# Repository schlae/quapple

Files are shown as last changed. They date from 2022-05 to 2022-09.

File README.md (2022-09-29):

# Quapple - A Quadlink Clone
What is a Quadlink? It's an ISA expansion card from the '80s designed to turn your IBM PC (such as a 5150 or 5160) into an Apple \]\[! After booting and running the software, you can switch quickly between PC and Apple mode using Ctrl-Alt-A (for Apple) and Ctrl-Alt-P (for PC).

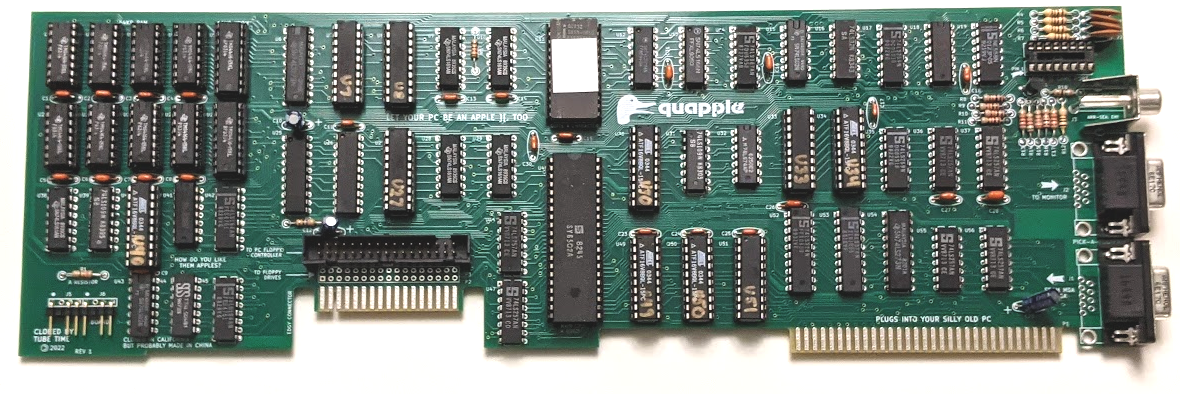
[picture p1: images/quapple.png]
Quapple card photo


I'm not selling this board, but the complete design files are available here so you can build it yourself. As an alternative, [a2heaven](http://www.a2heaven.com/webshop/index.php?rt=product/product&product_id=177) sells a kit with the PCB and all the components. (I have not personally built one of these kits.)

All of the components are readily available. In the bill of materials, Mouser part numbers are listed where available. The RAM chips, 27C32 ROM chip, and NE558 may be obtained from a variety of sources in China, but they are not guaranteed to work, so I recommend getting 1 or 2 extras just in case. Note: It has been reported that a Signetics NE558 with a date code of 8825VI, commonly available from China, does not actually work. If you can't find any working 558 chips, try building [my replacement that uses four 555 chips](https://oshpark.com/shared_projects/zHGURt7g).

[Schematic](https://github.com/schlae/quapple/blob/main/Quapple.pdf)

[Bill of Materials](https://github.com/schlae/quapple/blob/main/Quapple.csv)

Please note that the 0.1" header pins are *not* listed on the BOM. They are standard breakaway headers.

The memory chips (4416 and 4164 RAM) are both 150ns types.

[Fab Files](https://github.com/schlae/quapple/blob/main/fab/Quapple-rev1.zip)

## Fabrication Notes
This board is a straight forward 2-layer board. Ideally you should specify selective gold plating (hard gold) for the edge fingers, but this gets very expensive for small orders. ENIG will work but the gold will rub off fairly quickly.

Board dimensions are 13.335" x 4.24" (338.7mm x 107.7mm).

For the soldermask color, pick whatever you want!

## Assembly Notes
I recommend using sockets for the memory chips, CPU, and all the PALS. You'll also need a socket for the joystick/paddle connector. The list of sockets required is as follows:

| Quantity |  Position | Type |
|---|---|---|
| 9 | U1-U4, U20-U23, J4 | 16-pin, 0.3" wide |
| 2 | U5, U24 | 18-pin, 0.3" wide |
| 1 | U11 | 24-pin, 0.6" wide |
| 1 | U48 | 40-pin, 0.6" wide |
| 10 | U7, U8, U27, U30, U33, U34, U40, U49, U50, U51 | 20-pin, 0.3" wide |

If you plan to install the card in an IBM 5150 or 5160, you'll plug the floppy drive cable (the one going between the existing controller and the floppy drives in your computer) into the P2 edge connector on the card. **Solder a shrouded header at the J7 position with the keying notch pointing downwards.** Later on, you'll make a short cable to go between the floppy controller card and J7.

If you want to use the card in another system (note: I have not tested this yet!) with a standard IDC header instead of an edge card connector, **solder unshrouded headers at both the J7 and P3 position.** Your existing floppy cable will plug into P3, and you will need to make a short cable that connects J7 and your existing floppy controller card.

J5 and J6 are right-angle 0.1" headers. You can use a single 8-pin strip. Remember to pull pin 2 on both header positions since this is the key for the cable that plugs in. This is also marked on the back of the PC board.

If you are using an NMOS 6502, you can connect the solder jumper on the back of the board right next to the chip. CMOS 6502 chips repurpose this pin and the solder jumper should be left open.

Note for European users: it might be tempting to configure the solder jumpers on the back of the card for PAL timings rather than NTSC, but I have not tested this configuration. The original Quadlink has solder paste covering the jumpers, implying that they never fully tested it. Use it at your own risk.

## Bracket
I've created a CAD model of the original Quadlink bracket. If you have access to sheet metal tools (or even just a chassis nibbler) then you can reproduce it. Once it is in the right shape, bend the top using a press brake or even just a bench vise. The material is 0.035" (0.9mm) steel, brushed and painted black.

[CAD drawing of bracket](https://github.com/schlae/quapple/blob/main/mech/bracket.dxf)

## Programmable Devices
There are 11 programmable devices on the Quapple. One of them is a 27C32 EPROM which contains the character set for the text mode. I didn't have much luck using the Minipro TL866 device to program my Intel 2732 devices, so you might have to try a few to find one that works. You might also try using a flash device (28C32?) instead, but I have not tested this myself.

[EPROM binary](https://github.com/schlae/quapple/blob/main/eprom/U11QL100.bin)

The remaining programmable devices are all PALs. You can use an ATF16V8 (speed grade is unimportant here), which happens to be supported by the Minipro TL866.

[PAL files](https://github.com/schlae/quapple/tree/main/pals)

Use the JEDEC files (.jed) with the following Minipro command line under Linux:

`minipro -p "ATF16V8B" -w [file.jed] -P`

The full, commented, PAL source code is provided for educational purposes. If you want to modify them, you can use WinCUPL to build them.

I recommend marking the PALs with colored dots, labels, or permanent marker so you don't mix them up and put them in the wrong sockets.

PAL functions are as follows:

| Position | Function |
|---|---|
| U8 | Video address decoding (simple) |
| U27 | Video address decoding (complex). Video sync. |
| U7 | Clock generation |
| U30 | Soft switches |
| U33 | Color attribute generation |
| U34 | ISA bus address decoder |
| U40 | Disk controller |
| U49 | 6502 state machine |
| U50 | More soft switches |
| U51 | RAM/ROM mapping, CAS control, RESET inverter |

## Cable assemblies
You will also need to build several cable assemblies to connect the Quapple to your PC.

### Floppy drive cable
For use with an IBM 5150 or 5160, make a short, 6" (15cm) IDC ribbon cable, 34 pin, with a 0.1" female header at one end and a 34-pin female edge connector at the other end.

For any other computer, just crimp a 34-pin 0.1" female header at both ends. Be sure not to get pin 1 mixed up--it is very easy to do!

### Video loopback cable
To use the same monitor for both Apple and PC mode, you'll need a short cable to go between the Quapple and your regular video card (MDA or CGA). This is just a short cable with a male DE-9 connector at both ends, wired straight through (pin 1 to pin 1, etc).

The stock cable is 12" (30.5cm) long and uses a TE Connectivity/AMP 745032-1 connector, along with a cord guard, 207753-1, at both ends. The contact part number is 1-66506-0. The cable is 0.24" (6mm) diameter with eight conductors (the drain wire is connected to pin 1).

### PC speaker jumper
To hear Apple sound through the PC speaker, make a short 2-wire cable (maybe 2-3" long, depending on your computer). This goes from the motherboard to the Quapple.

The cable should be wired as follows:

* Pin 1 connects to pin 1 (black wire)
* Pin 2 is a key (plastic peg inserted in the opening) at both ends
* Pin 3 is not used
* Pin 4 to pin 4 (yellow wire)

## Installation
You'll want to install the card in the second-to-last slot (5150) or third-from-last slot (5160). This is because the floppy controller should be in between the Quapple and the power supply, just to make cable routing easier.

Before you start, plug the short floppy jumper cable into J7 on the Quapple. Also plug the 4-pin PC speaker jumper cable into header J6.

Remove the floppy controller and disconnect the drive cable from it. Plug the drive cable into the Quapple connector P2 (or P3, if the cable has a 0.1" socket at the end). Unplug the PC speaker from the motherboard.

Then plug the Quapple into the PC slot, managing the floppy cable as needed. The 4-pin jumper should plug into the motherboard's PC speaker header, and the PC speaker cable should plug into J5.

Then plug the short floppy jumper cable into the header on the floppy controller, and plug the floppy controller back into an adjacent slot. Since the card is shorter, it's much easier to use the slot that is closer to the power supply.

Finally, connect the DE-9 jumper cable between the video card and the *lower* connector on the Quapple. This step is optional since you can use the card with a dual monitor configuration, or even with the composite video output jack.

## Software
You can find the software at the link below, along with the manual of the original Quadlink. There are *three* disk images you will need: the Quadlink System Master, the Quadlink Filer, and DOS (I used PC DOS 1.10, but feel free to experiment). The Quadlink System Master disk has an executable, QUADLINK.EXE, which should be copied to the DOS disk.

The Filer disk can be written using a flux imaging tool, or possibly with an Apple II running ADTPro.

[Software download](https://www.diskman.com/presents/trackstar/software.htm)

A note about compatibility: I have only tested the card in an IBM 5150. It's supposed to work in a 5160 as well. Based on looking at the design, I see no reason why it wouldn't work in a faster machine, but there may be CPU-dependent hardware loops in the Quadlink executable that would prevent it from working.

Once you have the disks, insert the DOS disk and turn on the computer. After it boots, run QUADLINK.EXE and follow the prompts. When you insert the Filer disk, the software copies the entire Applesoft ROM from the disk into a special 16K memory on the card and write-protects it. Hit a key to get back to DOS, and then press CTRL-ALT-A. If you see the Quadlink banner, hit CTRL-ALT-DEL to boot the Apple.

## Troubleshooting
This can be a tricky card to troubleshoot. The QUADLINK.EXE doesn't really provide good error diagnostics, but if you can get it to access the Filer disk, then you know that the 6502 is running code and trying to copy data from the disk.

Someday, when I get a chance, I'll look into writing a diagnostic program to help with the process...

## License
This work is licensed under a Creative Commons Attribution-ShareAlike 4.0
International License. See [https://creativecommons.org/licenses/by-sa/4.0/](https://creativecommons.org/licenses/by-sa/4.0/).

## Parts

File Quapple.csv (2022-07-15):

Item | Qty | Reference(s) | Value | Mouser
1 | 23 | C1, C2, C3, C4, C5, C6, C7, C8, C11, C13, C14, C15, C16, C17, C18, C23, C24, C25, C26, C27, C28, C30, C31 | 0.1uF | 594-K104K15X7RF5TH5
2 | 1 | C9 | 0.1uF | 594-K104K15X7RF5TH5
3 | 3 | C10, C12, C29 | 6.8uF | 667-ECA-1HM100I
4 | 4 | C19, C20, C21, C22 | 0.02uF | 81-RDE7U3A203JUE1H3A
5 | 1 | J1 | PC VIDEO IN | 523-G17C0900132EU
6 | 1 | J2 | MONITOR OUT | 523-G17C0900132EU
7 | 1 | J3 | COMP | 502-3517PCX
8 | 1 | J4 | PADDLES | 517-4816-3004-CP
9 | 1 | J5 | TO SPEAKER | 538-22-28-6043
10 | 1 | J6 | FROM MOTHERBOARD | 538-22-28-6043
11 | 1 | J7 | PC_CTLR | 571-5103308-7
12 | 2 | JP1, JP2 | OPEN
13 | 1 | JP3 | SHORT
14 | 1 | JP4 | SHORT
15 | 1 | JP5 | OPEN
16 | 1 | JP6 | VPB
17 | 1 | P1 | Conn_ISA_8bit
18 | 1 | P2 | EDGE_TO_DRIVES
19 | 1 | P3 | TO_DRIVES | 571-5103308-7
20 | 1 | Q1 | 2N3904 | 610-2N3904
21 | 1 | R1 | 33 | 603-CFR-25JR-5233R
22 | 1 | R2 | 470 | 603-CFR-25JR-52470R
23 | 2 | R3, R15 | 3.3K | 603-CFR-25JR-523K3
24 | 5 | R4, R5, R6, R7, R12 | 100 | 603-CFR-25JR-52100R
25 | 4 | R8, R9, R10, R11 | 10K | 603-CFR-25JR-5210K
26 | 1 | R13 | 2.2K | 603-CFR-25JR-522K2
27 | 1 | R14 | 5.6K | 603-CFR-25JR-525K6
28 | 1 | R16 | 10K | 603-CFR-25JR-5210K
29 | 1 | R17 | 22K | 603-CFR-25JR-5222K
30 | 1 | R18 | 51 | 603-CFR-25JR-5251R
31 | 8 | U1, U2, U3, U4, U20, U21, U22, U23 | TMS4164
32 | 2 | U5, U24 | TMS4416
33 | 2 | U6, U54 | 74LS273 | 595-SN74LS273N
34 | 3 | U7, U33, U50 | PAL16R8 | 556-AF16V8CZ15PU
35 | 6 | U8, U27, U30, U34, U49, U51 | PAL16L8 | 556-AF16V8CZ15PU
36 | 5 | U9, U10, U28, U29, U38 | 74LS161 | 595-SN74LS161AN
37 | 1 | U11 | 27C32
38 | 1 | U12 | 74LS298 | 595-SN74LS298N
39 | 1 | U13 | 74LS166 | 595-SN74LS166AN
40 | 1 | U14 | 74LS367 | 595-SN74LS367AN
41 | 2 | U15, U43 | 74LS02 | 595-SN74LS02N
42 | 1 | U16 | 74LS32 | 595-SN74LS32N
43 | 2 | U17, U35 | 74LS259 | 595-SN74LS259BN
44 | 1 | U18 | 74LS251 | 595-SN74LS251N
45 | 1 | U19 | NE558
46 | 1 | U25 | 74LS373 | 595-SN74LS373N
47 | 1 | U26 | 74LS245 | 595-SN74LS245N
48 | 2 | U31, U39 | 74LS109 | 595-SN74LS109AN
49 | 1 | U32 | 74LS74 | 595-SN74LS74AN
50 | 6 | U36, U37, U46, U47, U55, U56 | 74LS257 | 595-SN74LS257BN
51 | 1 | U40 | PAL16R4 | 556-AF16V8CZ15PU
52 | 1 | U41 | 74LS38 | 595-SN74LS38N
53 | 2 | U42, U45 | 74LS194 | 595-SN74LS194AN
54 | 1 | U44 | 74LS04 | 595-SN74LS04N
55 | 1 | U48 | 6502 (NMOS) | 955-W65C02S6TPG-14
56 | 2 | U52, U53 | 74LS374 | 595-SN74LS374N

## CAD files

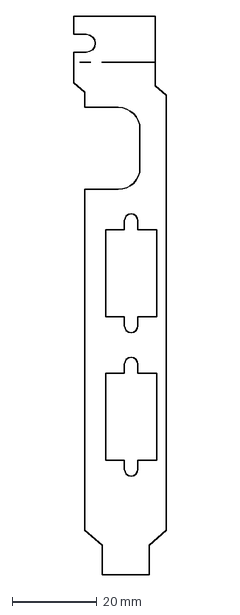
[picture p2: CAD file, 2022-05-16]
mech/bracket.dxf
21.8 x 131.4 mm

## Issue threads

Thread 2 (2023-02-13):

Intermittent operation

snhirsch, 2023-02-13:
Ok, so this is frustrating.  My newly-built Quapple worked the first time I put it in a 5150 and I was able to boot into the filer and DOS.  In the midst of testing, it started having problems writing to diskette.  From that point on, it refuses to boot.  When I hit return in Quadlink it tries a few times to read the FILER floppy before telling me it cannot read the diskette.  I reseated all the chips and swapped CPU.  No joy.  If I'm interpreting the writeup correctly, the seeks indicate the 6502 is executing code - is that correct?  If so, can you suggest a direction for diagnosis?  I have a fair amount of bench experience and own a scope and logic analyzer.

I recompiled the PLD sources for 8 of the 10 PLDs so I could target fused PALs (have a bunch of them).  But, the disk controller (U40) and clock generator (U7) are GAL16V8-20 per parts list.

schlae, 2023-02-13:
Since you had it working for a short time that makes me suspect either the drive itself or the Filer disk you're using, or perhaps the floppy data cable. You could try writing another Filer disk and going from there. If you have a logic analyzer, you could also connect a chip clip onto the disk decoding PAL and make sure you see signals that make sense.

But yes, if it tries to read from the disk then the 6502 is running code. That gets bootstrapped through the keyboard port (!) from the PC software side.

snhirsch, 2023-02-13:
Ok, good to know that something is running on the Quapple.  As a corrollary to my original question, do you have a guess as to why CUPL 4 won't compile the U40.PLD source?  I've attached the .LST and .DOC output files.  The latter complains of too many product terms.
[U40.zip](https://github.com/schlae/quapple/files/10723599/U40.zip)
This certainly isn't a showstopper, since I was able to program a GAL16V8 with your original JED, but my curiousity is getting the better of me.

I've already swapped the cabling and floppy drive and have re-written the media several times from a real Apple 2.  But it's possible the diskette is bad, so I'll revisit it.

snhirsch, 2023-02-14:
I'm starting to suspect an issue with the host machine.  When I hit <enter> to load FILER it accesses the A: drive briefly, then moves on to B:.  Need to dig out another floppy controller.  Working with Olde Hardware is always somewhat of an adventure.  But I did have another brief window of proper operation - so there's that.

snhirsch, 2023-02-15:
Well, not sure what was going on.  After numerous substitute cables and drives, I removed and shuffled boards in my 5150 to place the Quapple closest to the power supply.  Everything then started working and I cannot make it fail. So, I'll call this a success.  Thanks for your amazing reverse engineering work!

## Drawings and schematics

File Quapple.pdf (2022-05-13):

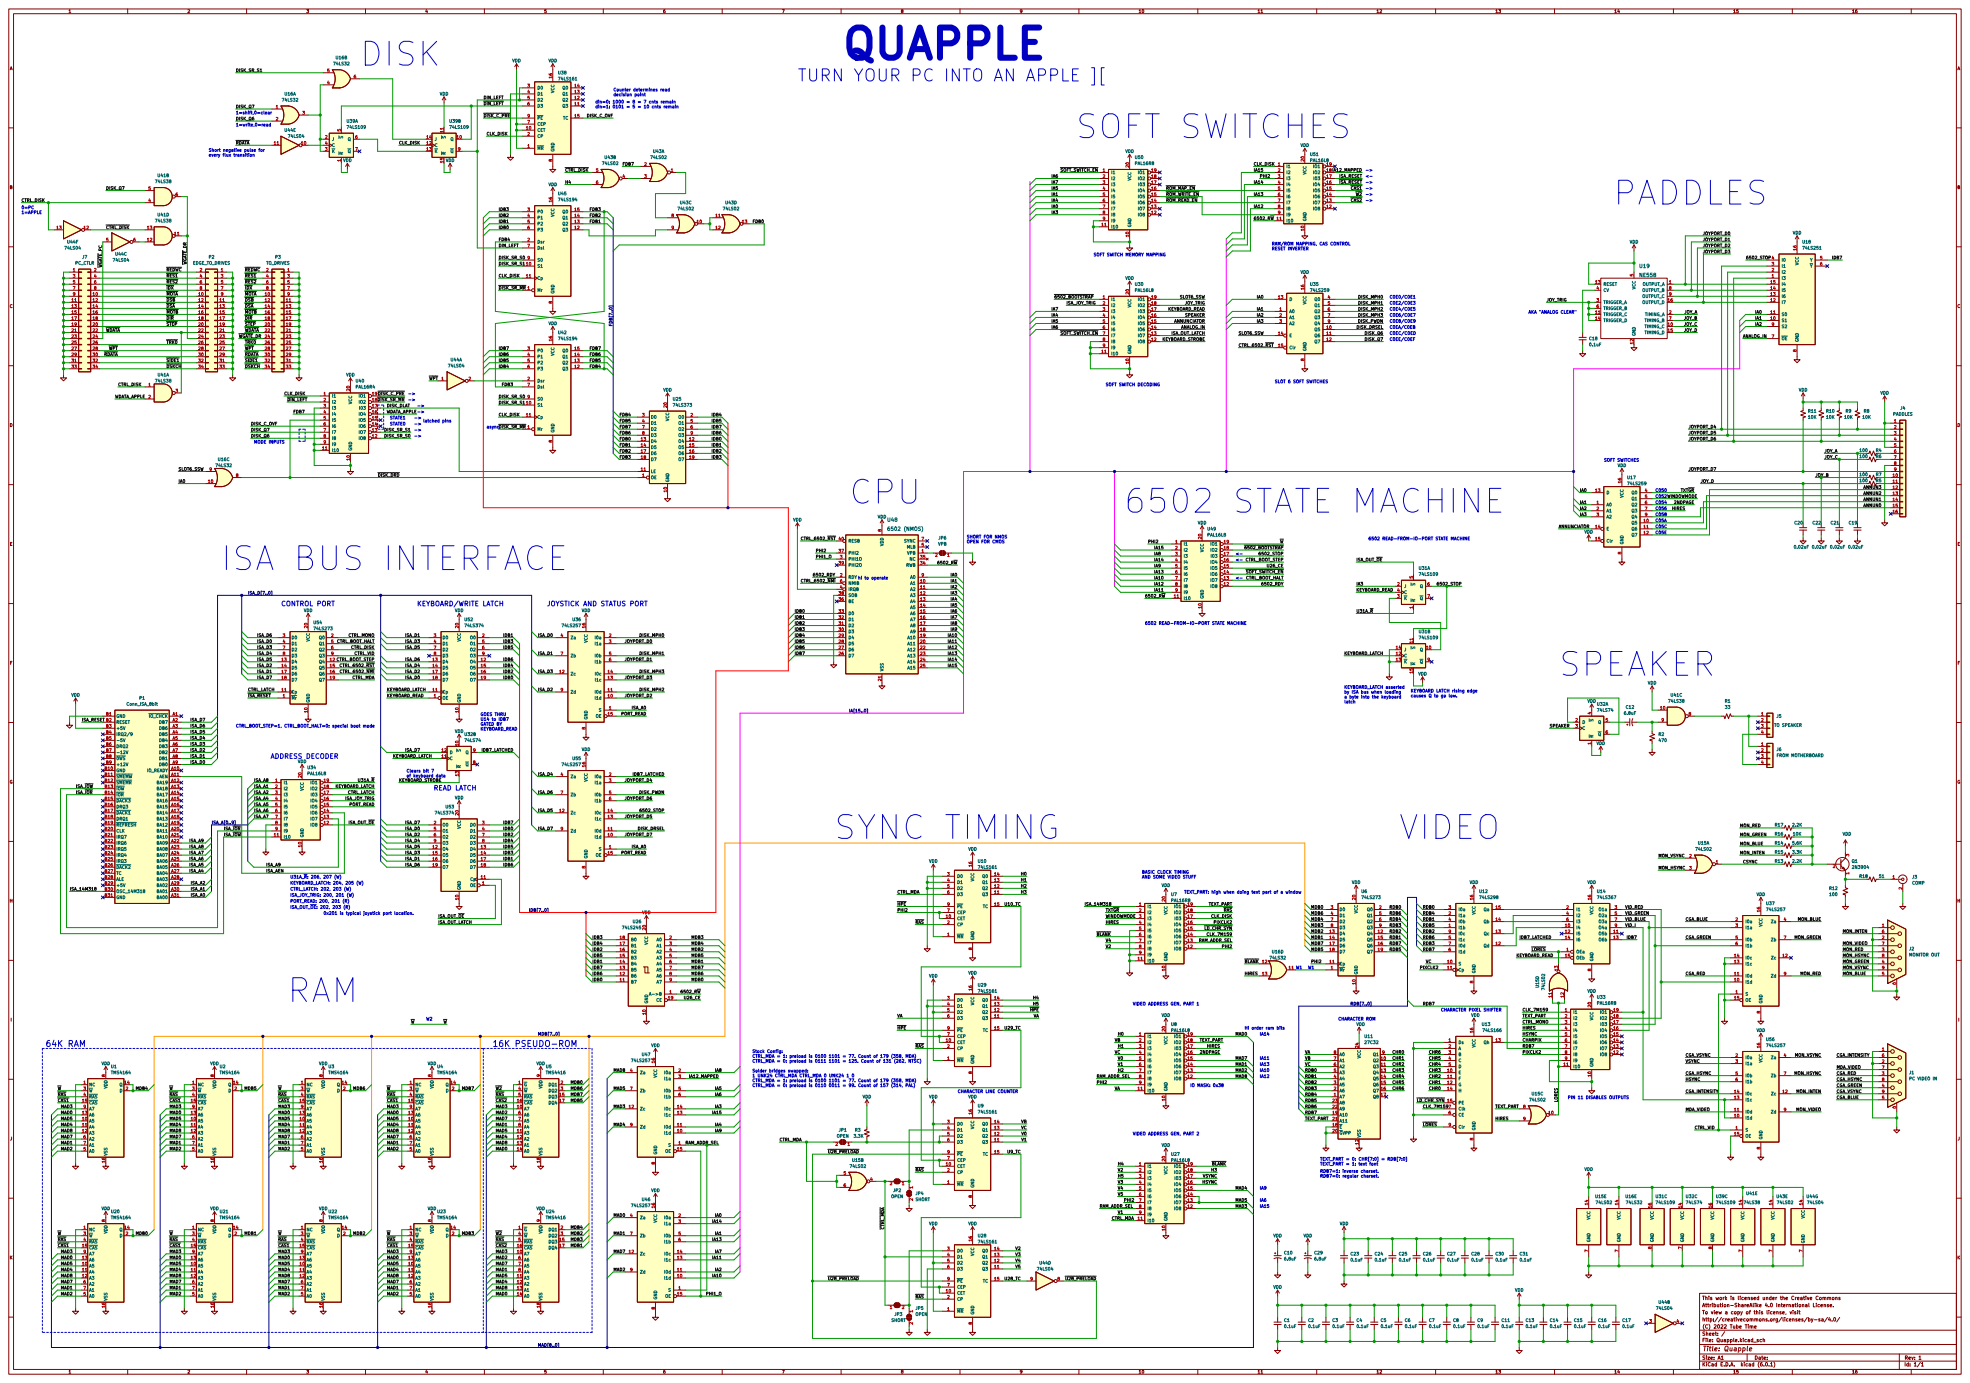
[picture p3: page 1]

SOFT SWITCHES TURN YOUR PC INTO AN APPLE ][

1=shift,0=clear Short negative pulse for

RAM/ROM MAPPING, CAS CONTROL RESET INVERTER 6502 STATE MACHINE

SOFT SWITCH MEMORY MAPPING

SHORT FOR NMOS OPEN FOR CMOS

6502 READ-FROM-IO-PORT STATE MACHINE

6502_RDY
PIN 11 DISABLES OUTPUTS SPEAKER

ISA_D1
ISA_D7
IO_READY A10 AEN A11 BA19 A12 BA18 A13 BA17 A14 BA16 A15 BA15 A16 BA14 A17 BA13 A18 BA12 A19 DB7 A2 BA11 A20 BA10 A21 BA09 A22 BA08 A23 BA07 A24 BA06 A25 BA05 A26 BA04 A27 BA03 A28 BA02 A29 DB6 A3 BA01 A30 BA00 A31 DB5 A4 DB4 A5 DB3 A6 DB2 A7 DB1 A8 DB0 A9 GND B1 GND B10 ~{SMEMW} B11 ~{SMEMR} B12 ~{IOW} B13 ~{IOR} B14 ~{DACK3} B15 DRQ3 B16 ~{DACK1} B17 DRQ1 B18 ~{REFRESH} B19 RESET B2 CLK B20

KEYBOARD_LATCH asserted
by ISA bus when loading
a byte into the keyboard

KEYBOARD LATCH rising edge
causes Q to go low.

GOES THRU U14 to IDB7 GATED BY
ISA_D1 KEYBOARD_LATCH

AND SOME VIDEO STUFF Clears bit 7
of keyboard data

0x201 is typical joystick port location.

VIDEO ADDRESS GEN, PART 1

Stock Config:
CTRL_MDA = 1: preload is 0100 1101 = 77. Count of 179 (358, MDA)
CTRL_MDA = 0: preload is 0111 1101 = 125. Count of 131 (262, NTSC)

Solder bridges swapped: 1 UNK24 CTRL_MDA CTRL_MDA 0 UNK24 1 0 CTRL_MDA = 1: preload is 0100 1101 = 77. Count of 179 (358, MDA)

CTRL_MDA = 0: preload is 0110 0011 = 99. Count of 157 (314, PAL)

VIDEO ADDRESS GEN, PART 2

To view a copy of this license, visit Attribution-ShareAlike 4.0 International License. This work is licensed under the Creative Commons S

RDB7=1: inverse charset. RDB7=0: regular charset.

http://creativecommons.org/licenses/by-sa/4.0/
File: Quapple.kicad_sch Sheet: / (C) 2022 Tube Time

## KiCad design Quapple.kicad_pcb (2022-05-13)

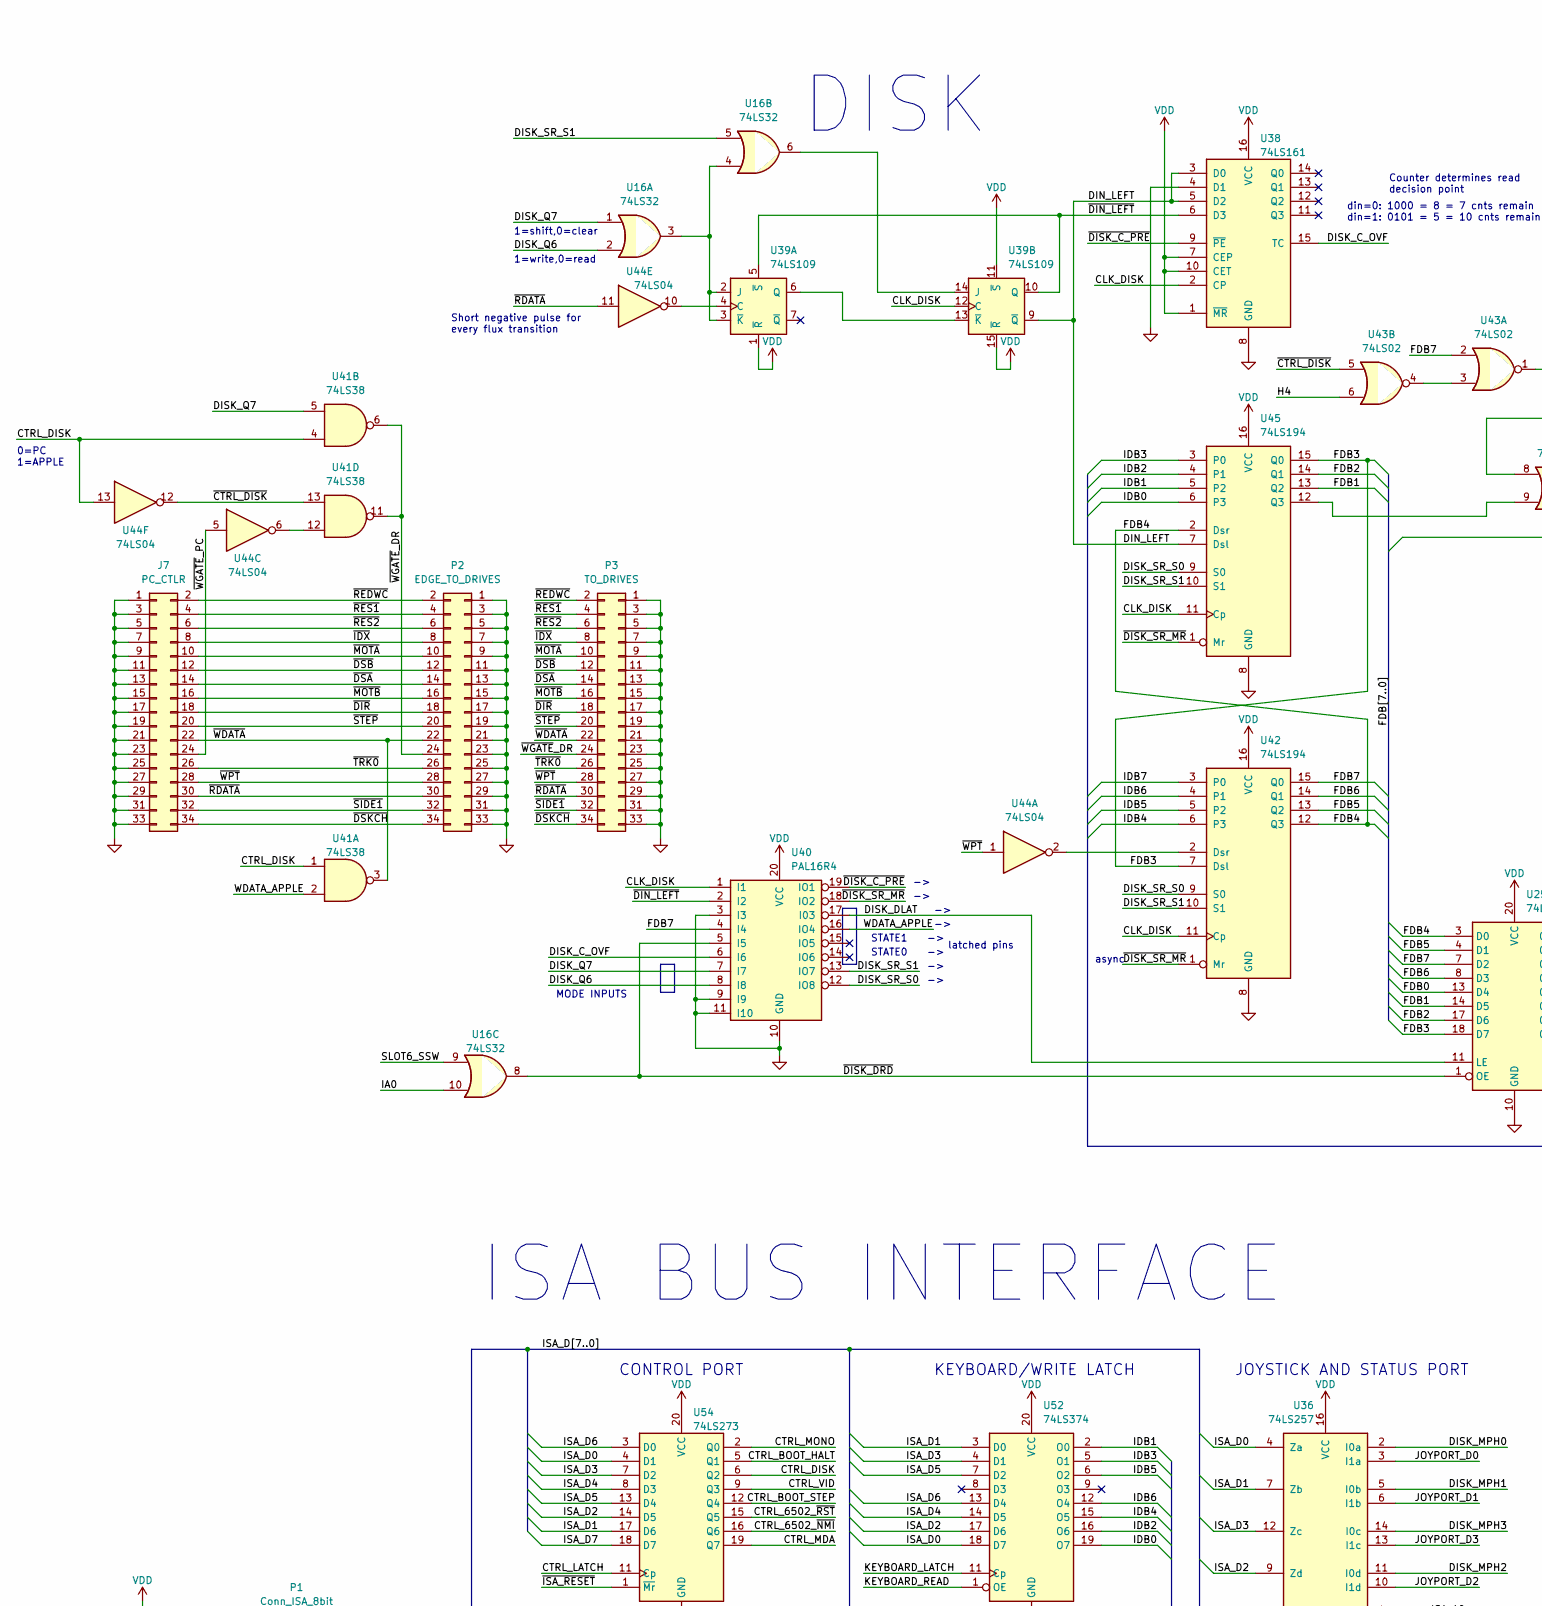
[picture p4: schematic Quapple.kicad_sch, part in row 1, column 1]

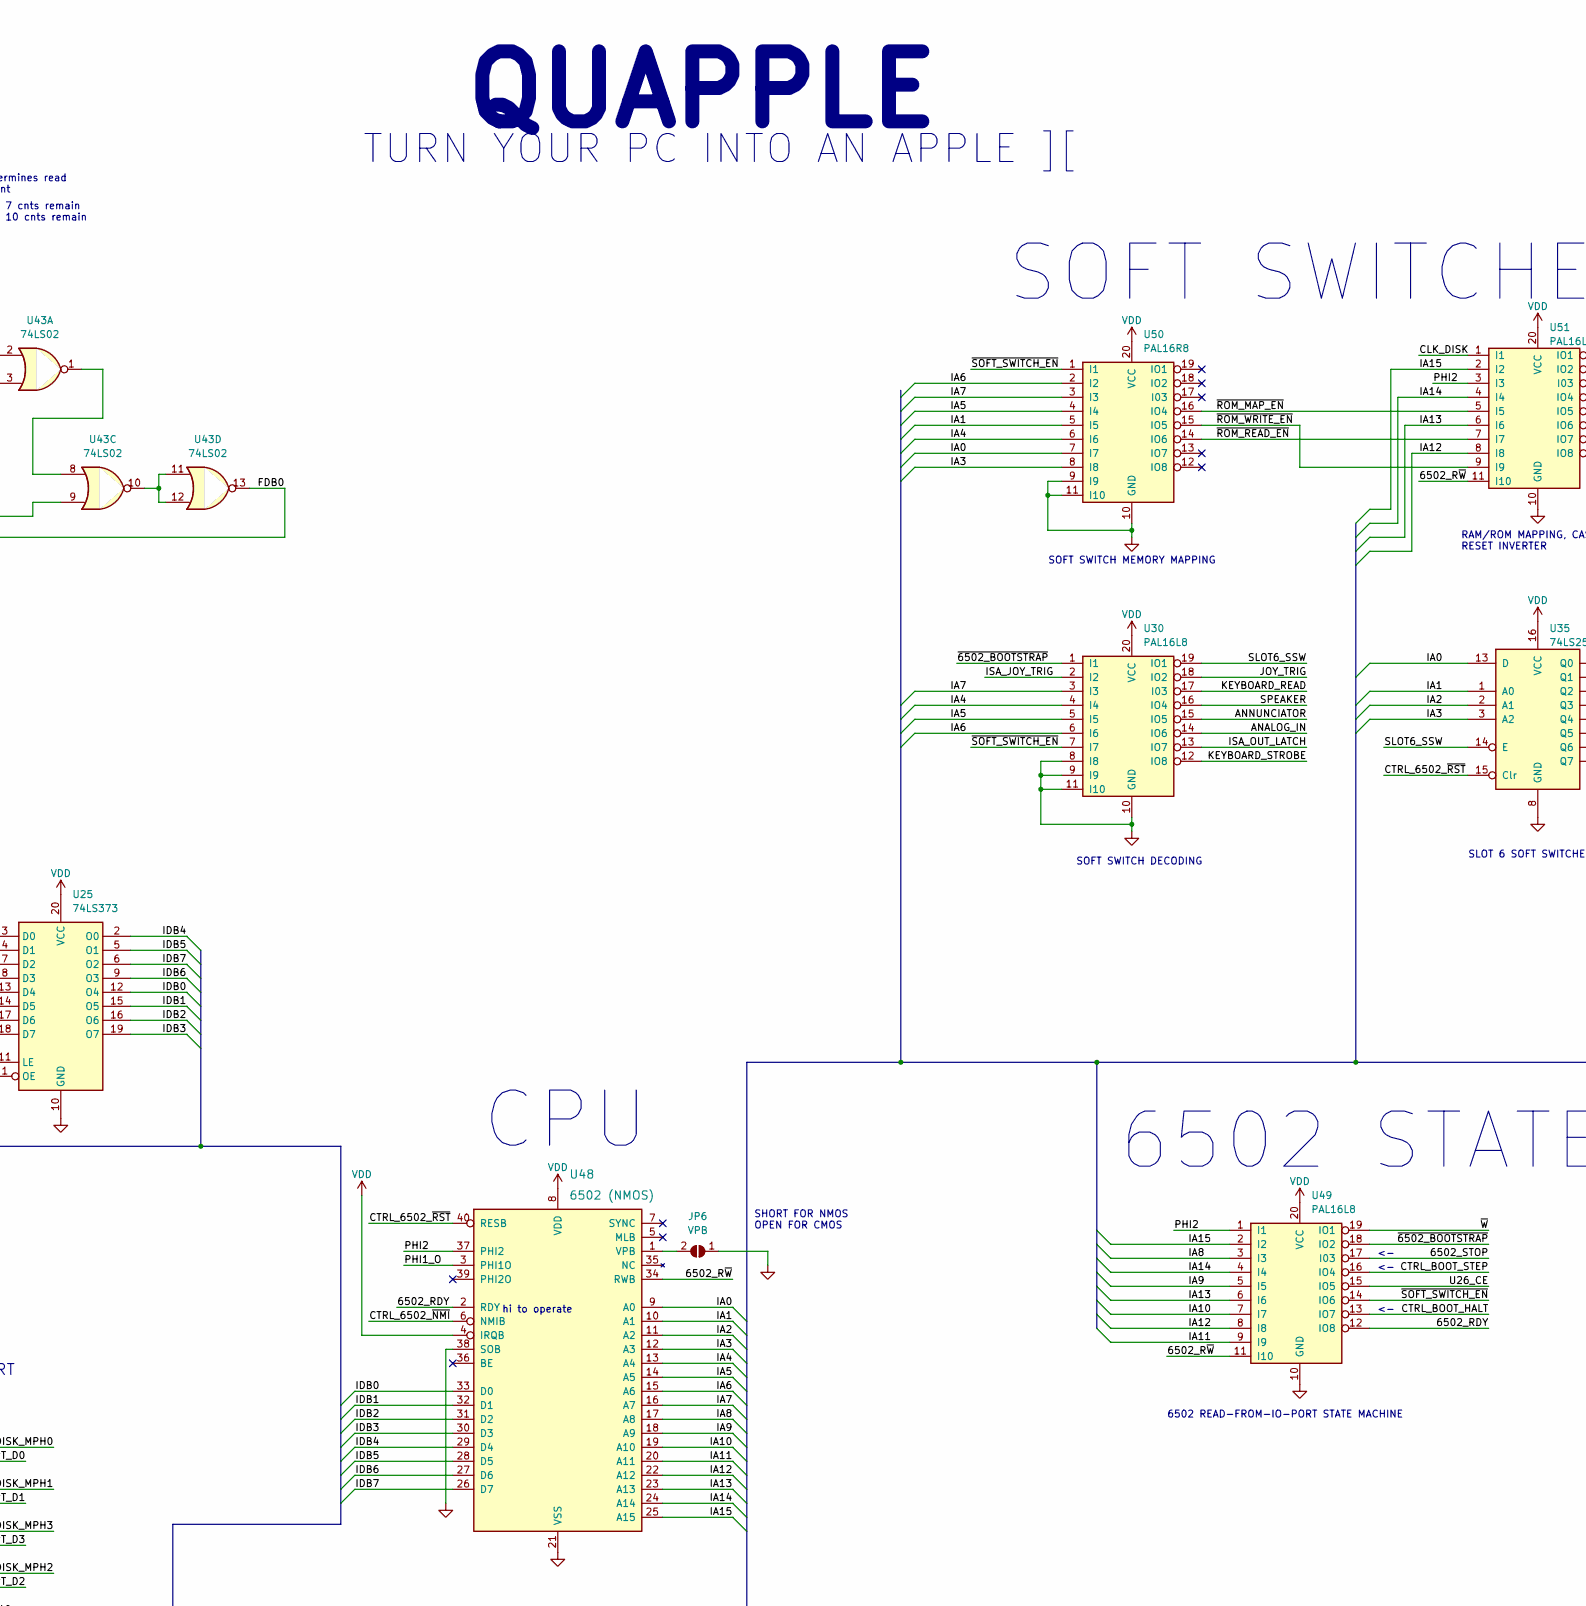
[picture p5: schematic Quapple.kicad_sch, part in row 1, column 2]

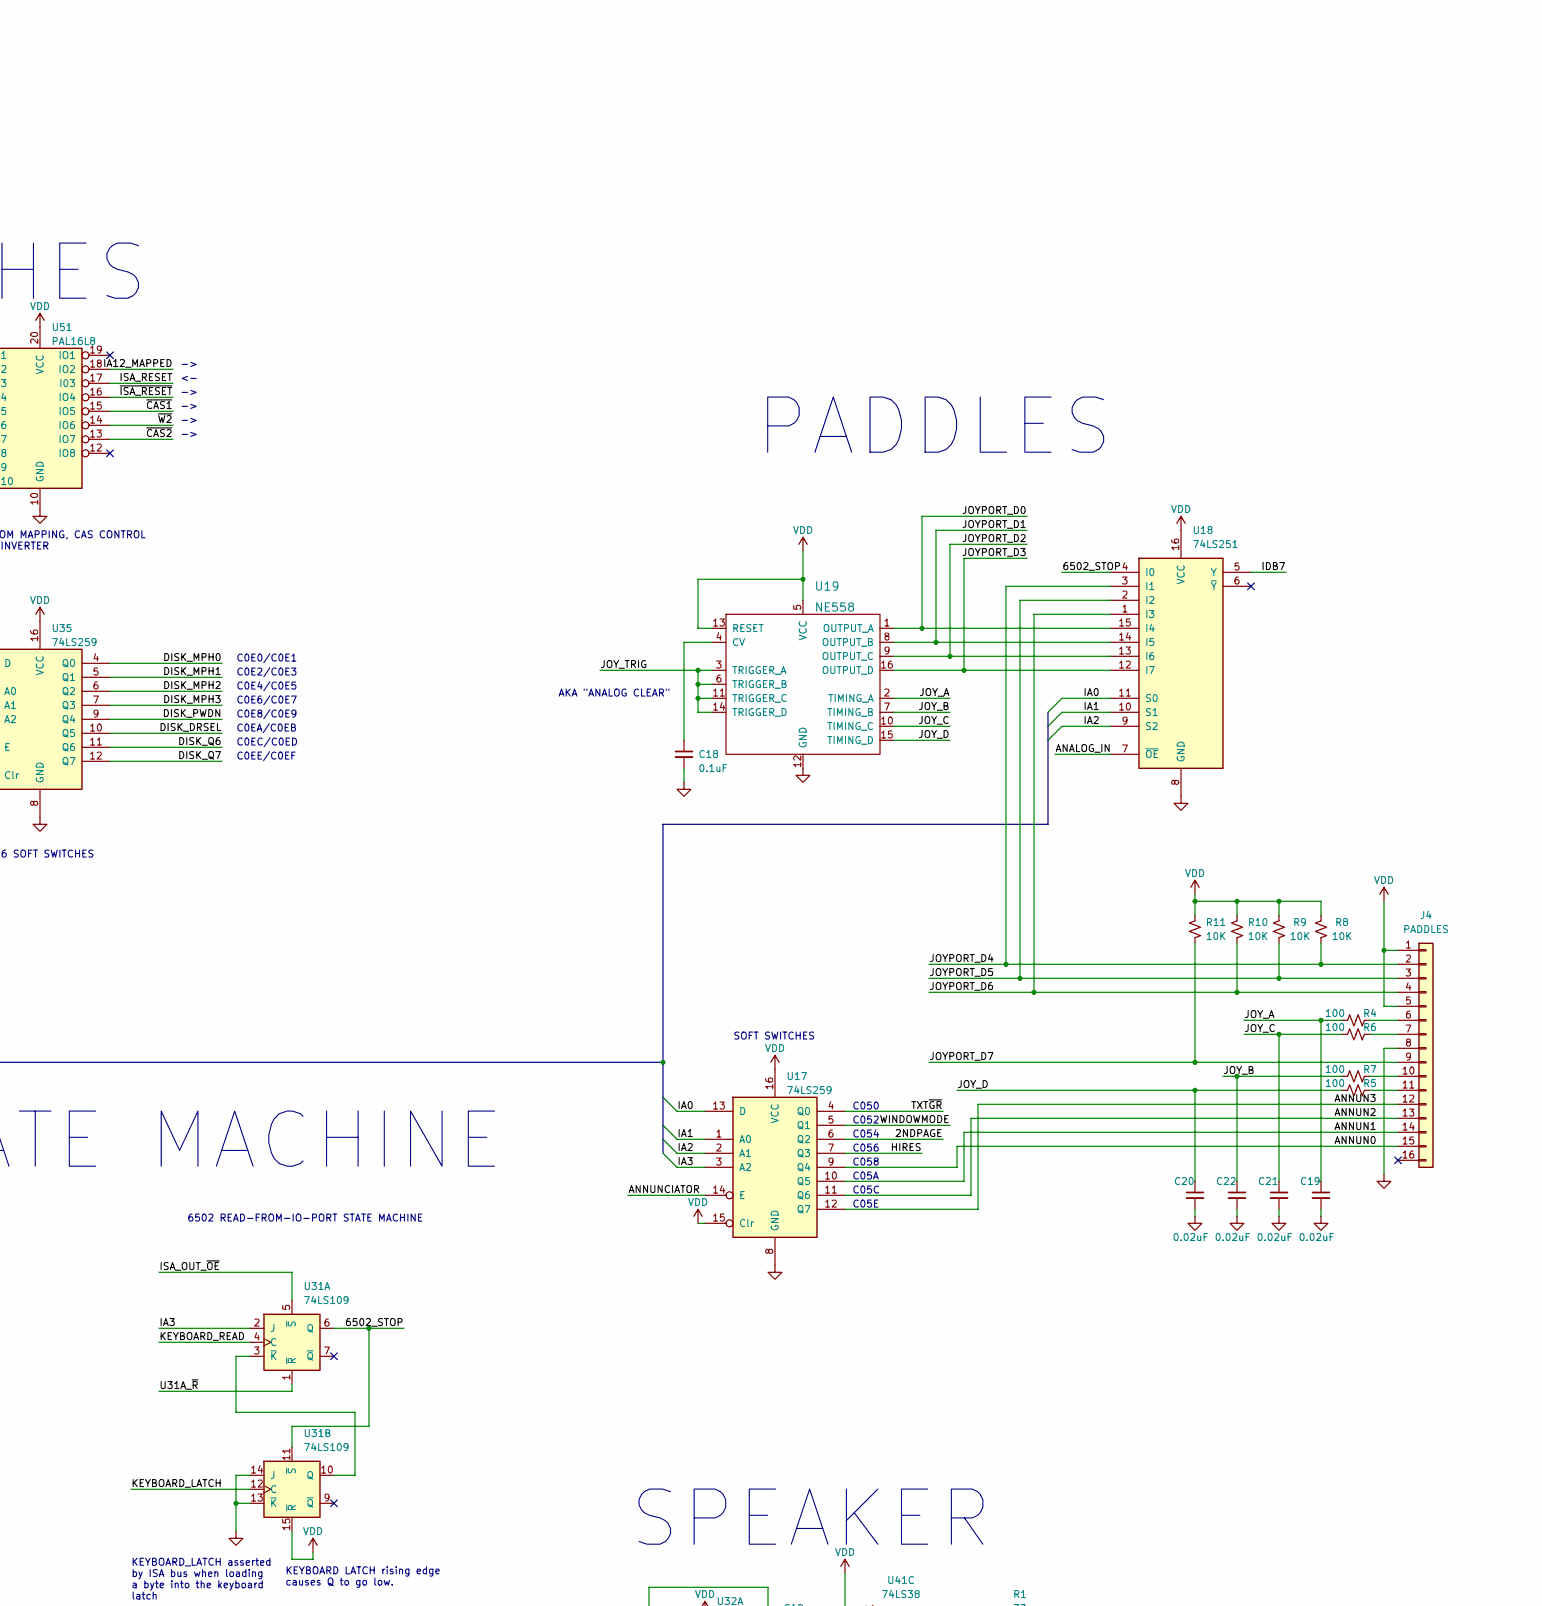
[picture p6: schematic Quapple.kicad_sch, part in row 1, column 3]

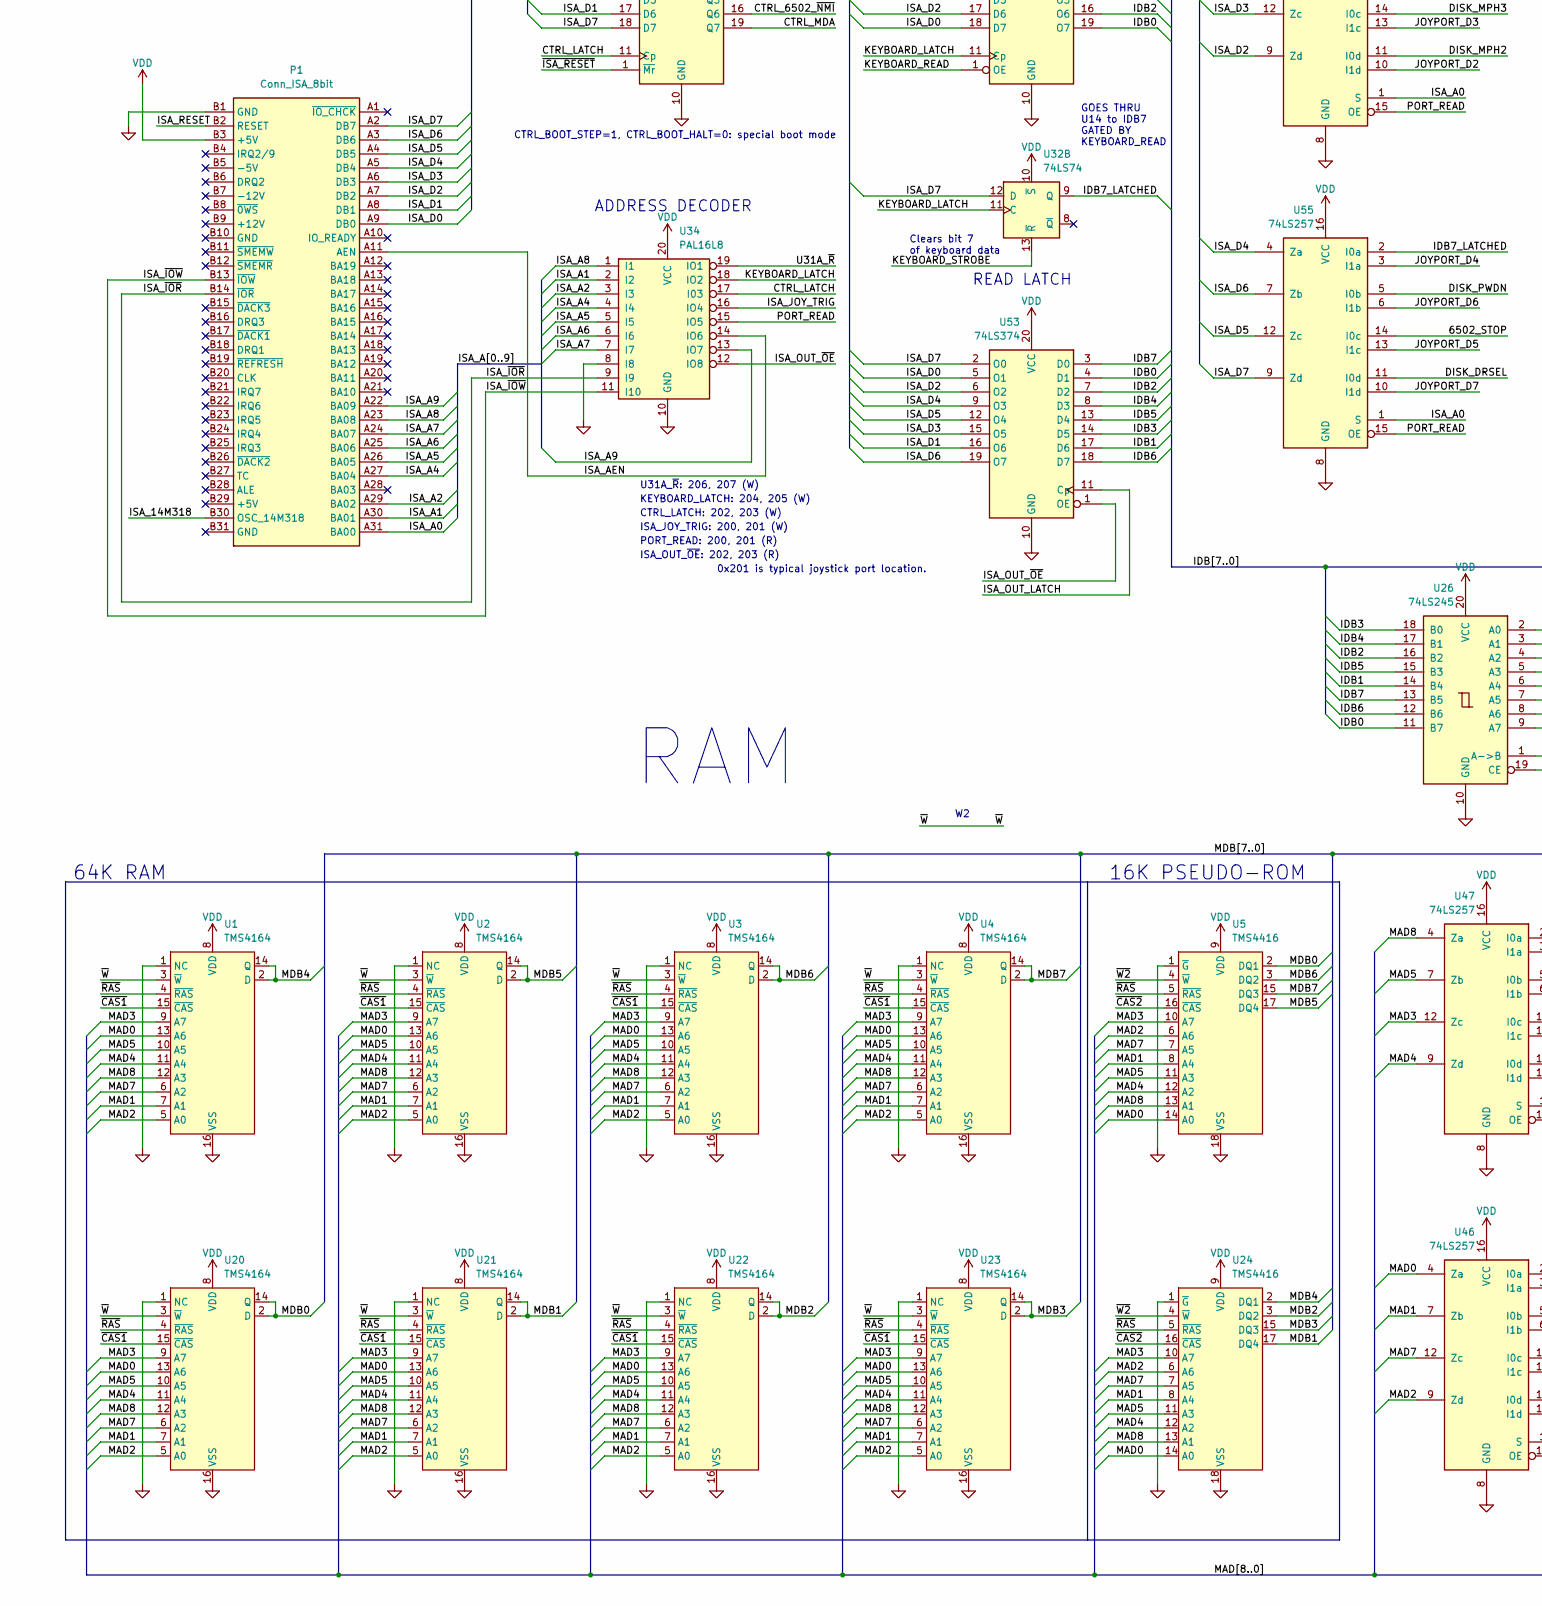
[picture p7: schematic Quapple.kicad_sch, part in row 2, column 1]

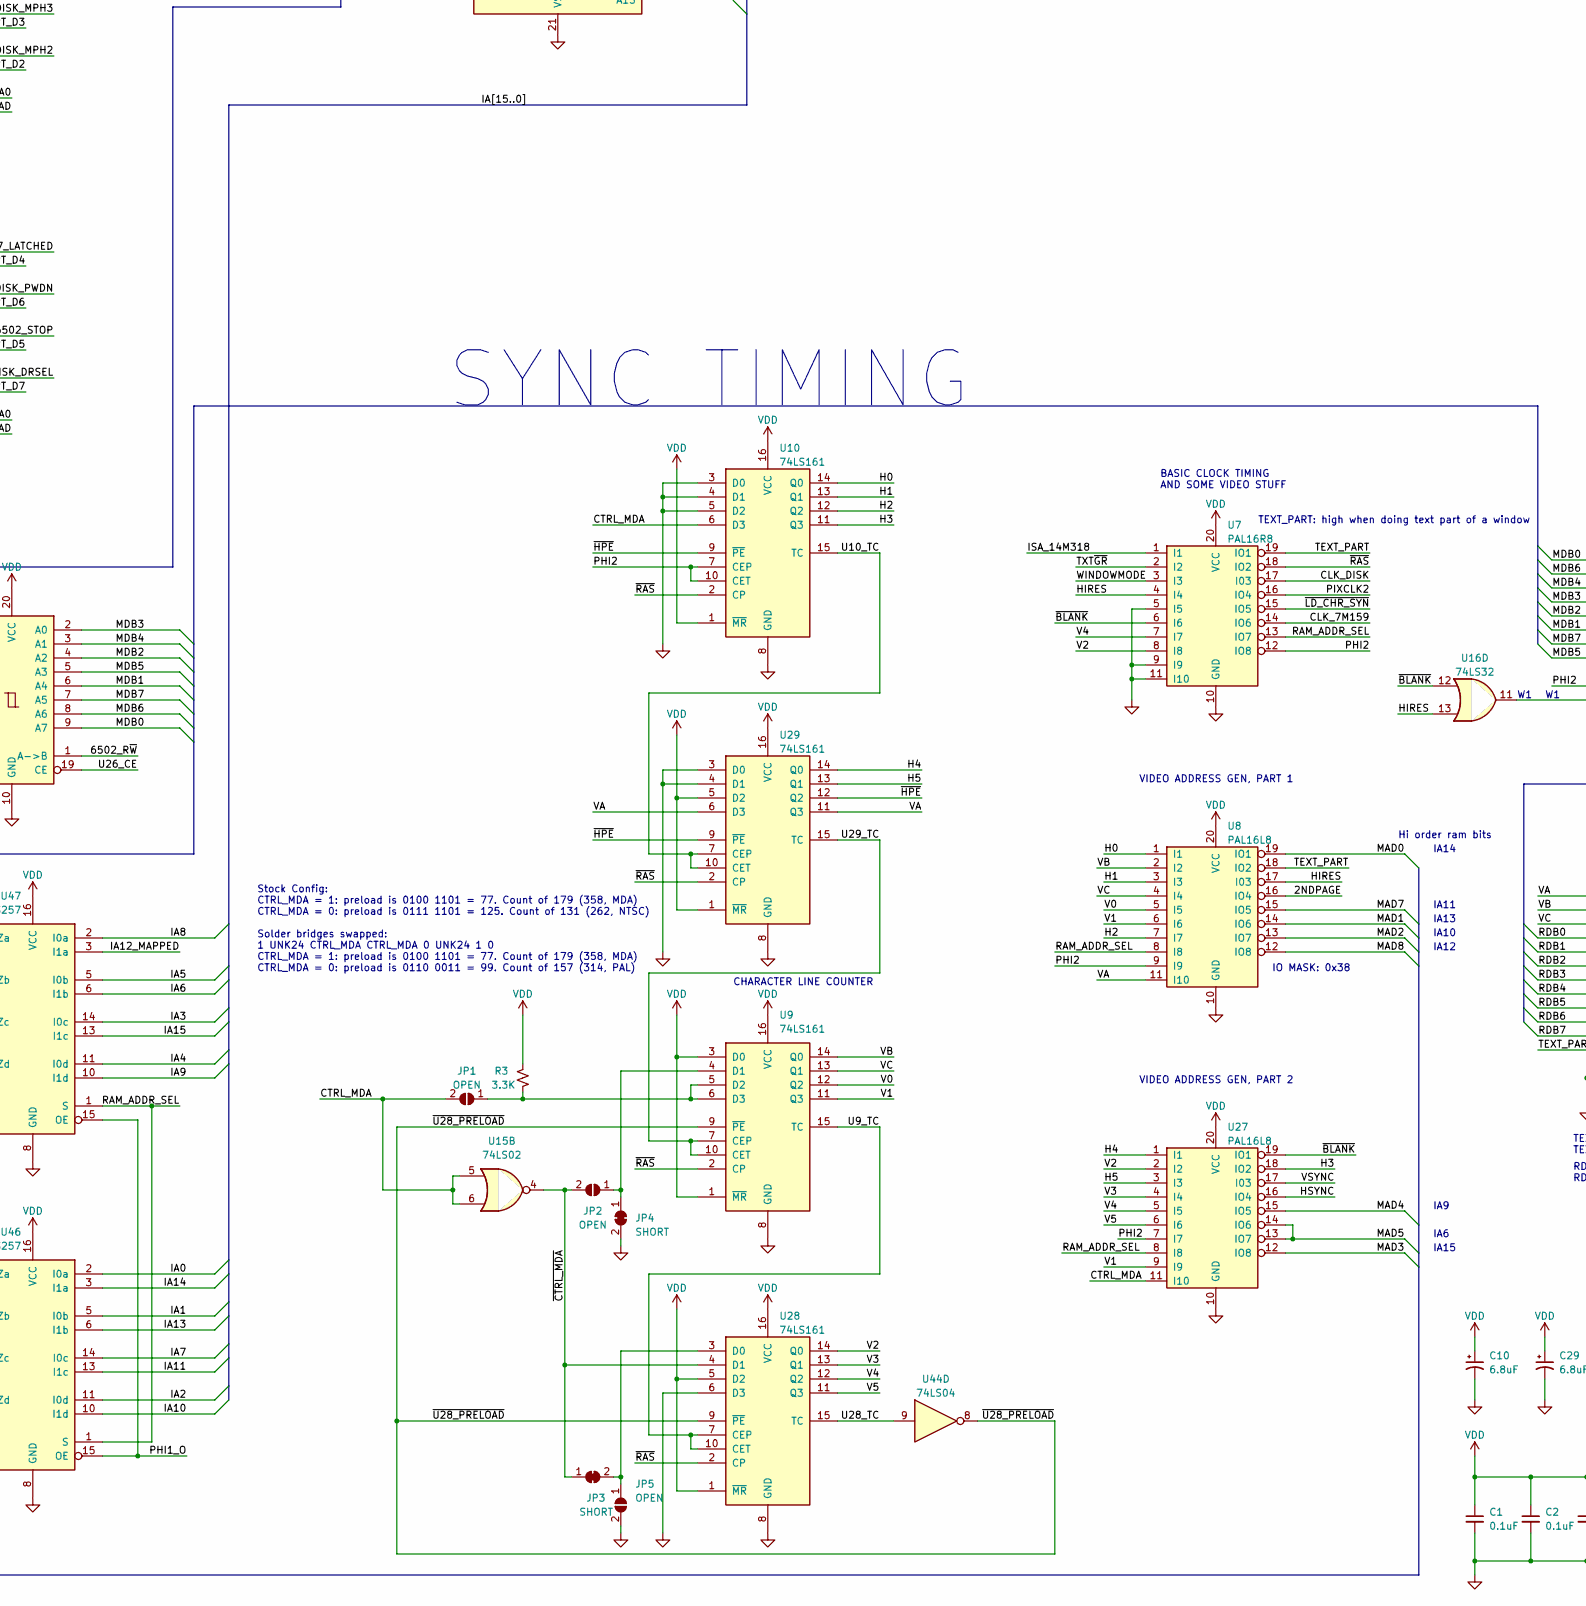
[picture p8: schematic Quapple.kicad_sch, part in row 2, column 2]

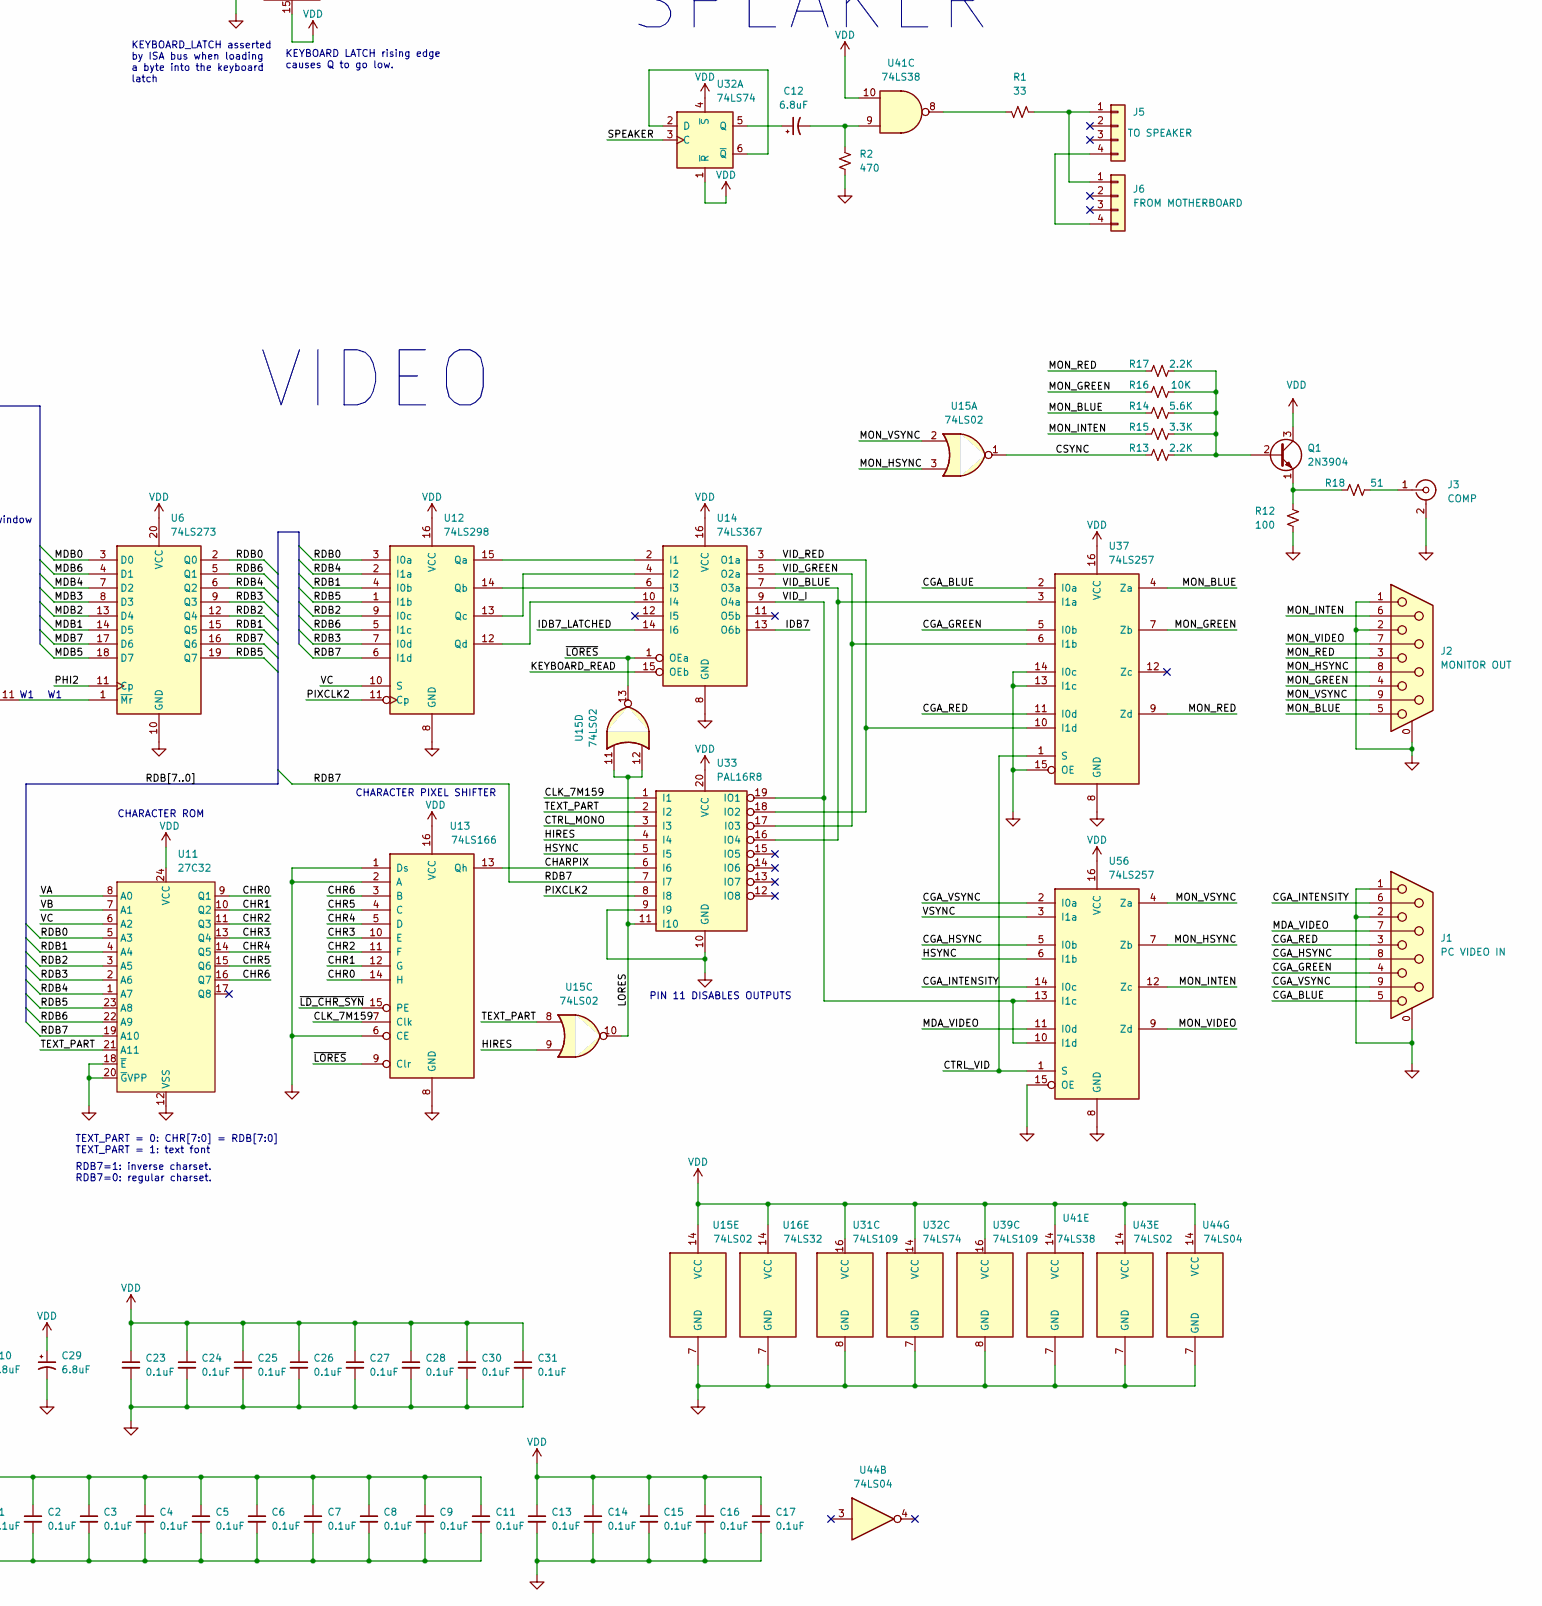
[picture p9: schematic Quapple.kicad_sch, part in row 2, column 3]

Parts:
C1, C2, C3, C4, C5, C6, C7, C8, C11, C13, C14, C15, C16, C17, C18, C23, C24, C25, C26, C27, C28, C30, C31: 0.1uF; CAP300; Mouser 594-K104K15X7RF5TH5
C9: 0.1uF; CAP300_THIN; Mouser 594-K104K15X7RF5TH5
C10, C12, C29: 6.8uF; CAP300_P; Mouser 667-ECA-1HM100I
C19, C20, C21, C22: 0.02uF; CAP300_THIN; Mouser 81-RDE7U3A203JUE1H3A
J1: PC VIDEO IN; DB9; Mouser 523-G17C0900132EU
J2: MONITOR OUT; DB9; Mouser 523-G17C0900132EU
J3: COMP; RCA_JACK; Mouser 502-3517PCX
J4: PADDLES; DIP16_ALT; Mouser 517-4816-3004-CP
J5: TO SPEAKER; HDR100-4; Mouser 538-22-28-6043
J6: FROM MOTHERBOARD; HDR100-4; Mouser 538-22-28-6043
J7: PC_CTLR; HDR100-34; Mouser 571-5103308-7
JP1, JP2: OPEN; BRIDGE1_O
JP3: SHORT; BRIDGE3_S
JP4: SHORT; BRIDGE2_S
JP5: OPEN; BRIDGE4
JP6: VPB; BRIDGE1_O
P1: Conn_ISA_8bit; EDGE_ISA_8BIT
P2: EDGE_TO_DRIVES; EDGE_34
P3: TO_DRIVES; HDR100-34; Mouser 571-5103308-7
Q1: 2N3904; TO92; Mouser 610-2N3904
R1: 33; RES500; Mouser 603-CFR-25JR-5233R
R2: 470; RES500; Mouser 603-CFR-25JR-52470R
R3, R15: 3.3K; RES500; Mouser 603-CFR-25JR-523K3
R4, R5, R6, R7, R12: 100; RES500; Mouser 603-CFR-25JR-52100R
R8, R9, R10, R11: 10K; RES420; Mouser 603-CFR-25JR-5210K
R13, R17: 2.2K; RES500; Mouser 603-CFR-25JR-522K2
R14: 5.6K; RES500; Mouser 603-CFR-25JR-525K6
R16: 10K; RES500; Mouser 603-CFR-25JR-5210K
R18: 51; RES420; Mouser 603-CFR-25JR-5251R
U1, U2, U3, U4, U20, U21, U22, U23: TMS4164; DIP16
U5, U24: TMS4416; DIP18
U6, U54: 74LS273; DIP20; Mouser 595-SN74LS273N
U7, U33, U50: PAL16R8; DIP20; Mouser 556-AF16V8CZ15PU
U8, U27, U30, U34, U49, U51: PAL16L8; DIP20; Mouser 556-AF16V8CZ15PU
U9, U10, U28, U29, U38: 74LS161; DIP16; Mouser 595-SN74LS161AN
U11: 27C32; DIP24
U12: 74LS298; DIP16; Mouser 595-SN74LS298N
U13: 74LS166; DIP16; Mouser 595-SN74LS166AN
U14: 74LS367; DIP16; Mouser 595-SN74LS367AN
U15, U43: 74LS02; DIP14; Mouser 595-SN74LS02N
U16: 74LS32; DIP14; Mouser 595-SN74LS32N
U17, U35: 74LS259; DIP16; Mouser 595-SN74LS259BN
U18: 74LS251; DIP16; Mouser 595-SN74LS251N
U19: NE558; DIP16
U25: 74LS373; DIP20; Mouser 595-SN74LS373N
U26: 74LS245; DIP20; Mouser 595-SN74LS245N
U31, U39: 74LS109; DIP16; Mouser 595-SN74LS109AN
U32: 74LS74; DIP14; Mouser 595-SN74LS74AN
U36, U37, U46, U47, U55, U56: 74LS257; DIP16; Mouser 595-SN74LS257BN
U40: PAL16R4; DIP20; Mouser 556-AF16V8CZ15PU
U41: 74LS38; DIP14; Mouser 595-SN74LS38N
U42, U45: 74LS194; DIP16; Mouser 595-SN74LS194AN
U44: 74LS04; DIP14; Mouser 595-SN74LS04N
U48: 6502 (NMOS); DIP40; Mouser 955-W65C02S6TPG-14
U52, U53: 74LS374; DIP20; Mouser 595-SN74LS374N

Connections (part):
/2NDPAGE: U8.16 (IO4), U17.6 (Q2)
/6502_RDY: U48.2 (RDY), U49.12 (IO8)
/6502_R~W: U26.1 (A->B), U48.34 (RWB), U49.11 (I10), U51.11 (I10)
/6502_STOP: U18.4 (I0), U31.6 (Q), U31.11 (~S), U49.17 (I03), U55.14 (I0c)
/ANALOG_IN: U18.7 (~OE), U30.14 (IO6)
/ANNUN0: J4.15, U17.9 (Q4)
/ANNUN1: J4.14, U17.10 (Q5)
/ANNUN2: J4.13, U17.11 (Q6)
/ANNUN3: J4.12, U17.12 (Q7)
/ANNUNCIATOR: U17.14 (E), U30.15 (IO5)
/CGA_BLUE: J1.5, U37.2 (I0a)
/CGA_GREEN: J1.4, U37.5 (I0b)
/CGA_HSYNC: J1.8, U56.5 (I0b)
/CGA_INTENSITY: J1.6, U56.14 (I0c)
/CGA_RED: J1.3, U37.11 (I0d)
/CGA_VSYNC: J1.9, U56.2 (I0a)
/CHARPIX: U13.13 (Qh), U33.6 (I6)
/CHR0: U11.9 (Q1), U13.14 (H)
/CHR1: U11.10 (Q2), U13.12 (G)
/CHR2: U11.11 (Q3), U13.11 (F)
/CHR3: U11.13 (Q4), U13.10 (E)
/CHR4: U11.14 (Q5), U13.5 (D)
/CHR5: U11.15 (Q6), U13.4 (C)
/CHR6: U11.16 (Q7), U13.3 (B)
/CLK_7M159: U7.14 (IO6), U13.7 (Clk), U33.1 (I1)
/CLK_DISK: U7.17 (I03), U38.2 (CP), U39.12 (C), U40.1 (I1), U42.11 (Cp), U45.11 (Cp), U51.1 (I1)
/CSYNC: R13.1, U15.1
/CTRL_6502_~NMI: U48.6 (NMIB), U54.16 (Q6)
/CTRL_6502_~RST: U35.15 (Clr), U48.40 (RESB), U54.15 (Q5)
/CTRL_BOOT_HALT: U49.13 (IO7), U54.5 (Q1)
/CTRL_BOOT_STEP: U49.16 (IO4), U54.12 (Q4)
/CTRL_DISK: U41.1, U41.4, U44.13, U54.6 (Q2)
/CTRL_LATCH: U34.17 (I03), U54.11 (Cp)
/CTRL_MDA: JP1.2 (B), U10.6 (D3), U15.5, U15.6, U27.11 (I10), U54.19 (Q7)
/CTRL_MONO: U33.3 (I3), U54.2 (Q0)
/CTRL_VID: U37.1 (S), U54.9 (Q3), U56.1 (S)
/DIN_LEFT: U38.3 (D0), U38.5 (D2), U39.9 (~Q), U45.7 (Dsl)
/DISK_C_OVF: U38.15 (TC), U40.6 (I6)
/DISK_DLAT: U25.11 (LE), U40.17 (I03)
/DISK_DRSEL: U35.10 (Q5), U55.11 (I0d)
/DISK_MPH0: U35.4 (Q0), U36.2 (I0a)
/DISK_MPH1: U35.5 (Q1), U36.5 (I0b)
/DISK_MPH2: U35.6 (Q2), U36.11 (I0d)
/DISK_MPH3: U35.7 (Q3), U36.14 (I0c)
/DISK_PWDN: U35.9 (Q4), U55.5 (I0b)
/DISK_Q6: U16.2, U35.11 (Q6), U40.8 (I8)
/DISK_Q7: U16.1, U35.12 (Q7), U40.7 (I7), U41.5
/DISK_SR_S0: U40.12 (IO8), U42.9 (S0), U45.9 (S0)
/DISK_SR_S1: U16.5, U40.13 (IO7), U42.10 (S1), U45.10 (S1)
/FDB0: U25.13 (D4), U43.13
/FDB1: U25.14 (D5), U45.13 (Q2)
/FDB2: U25.17 (D6), U45.14 (Q1)
/FDB3: U25.18 (D7), U42.7 (Dsl), U45.15 (Q0)
/FDB4: U25.3 (D0), U42.12 (Q3), U45.2 (Dsr)
/FDB5: U25.4 (D1), U42.13 (Q2)
/FDB6: U25.8 (D3), U42.14 (Q1)
/FDB7: U25.7 (D2), U40.4 (I4), U42.15 (Q0), U43.2
/H0: U8.1 (I1), U10.14 (Q0)
/H1: U8.3 (I3), U10.13 (Q1)
/H2: U8.7 (I7), U10.12 (Q2)
/H3: U10.11 (Q3), U27.18 (IO2)
/H4: U27.1 (I1), U29.14 (Q0), U43.6
/H5: U27.3 (I3), U29.13 (Q1)
/HIRES: U7.4 (I4), U8.17 (I03), U15.9, U16.13, U17.7 (Q3), U33.4 (I4)
/HSYNC: U27.16 (IO4), U33.5 (I5), U56.6 (I1b)
/IA0: U16.10, U17.13 (D), U18.11 (S0), U35.13 (D), U46.2 (I0a), U48.9 (A0), U50.7 (I7)
/IA1: U17.1 (A0), U18.10 (S1), U35.1 (A0), U46.5 (I0b), U48.10 (A1), U50.5 (I5)
/IA2: U17.2 (A1), U18.9 (S2), U35.2 (A1), U46.11 (I0d), U48.11 (A2)
/IA3: U17.3 (A2), U31.2 (J), U35.3 (A2), U47.14 (I0c), U48.12 (A3), U50.8 (I8)
/IA4: U30.4 (I4), U47.11 (I0d), U48.13 (A4), U50.6 (I6)
/IA5: U30.5 (I5), U47.5 (I0b), U48.14 (A5), U50.4 (I4)
/IA6: U30.6 (I6), U47.6 (I1b), U48.15 (A6), U50.2 (I2)
/IA7: U30.3 (I3), U46.14 (I0c), U48.16 (A7), U50.3 (I3)
/IA8: U47.2 (I0a), U48.17 (A8), U49.3 (I3)
/IA9: U47.10 (I1d), U48.18 (A9), U49.5 (I5)
/IA10: U46.10 (I1d), U48.19 (A10), U49.7 (I7)
/IA11: U46.13 (I1c), U48.20 (A11), U49.9 (I9)
/IA12: U48.22 (A12), U49.8 (I8), U51.8 (I8)
/IA12_MAPPED: U47.3 (I1a), U51.18 (IO2)
/IA13: U46.6 (I1b), U48.23 (A13), U49.6 (I6), U51.6 (I6)
/IA14: U46.3 (I1a), U48.24 (A14), U49.4 (I4), U51.4 (I4)
/IA15: U47.13 (I1c), U48.25 (A15), U49.2 (I2), U51.2 (I2)
/IDB0: U25.12 (O4), U26.11 (B7), U45.6 (P3), U48.33 (D0), U52.19 (O7), U53.4 (D1)
/IDB1: U25.15 (O5), U26.14 (B4), U45.5 (P2), U48.32 (D1), U52.2 (O0), U53.17 (D6)
/IDB2: U25.16 (O6), U26.16 (B2), U45.4 (P1), U48.31 (D2), U52.16 (O6), U53.7 (D2)
/IDB3: U25.19 (O7), U26.18 (B0), U45.3 (P0), U48.30 (D3), U52.5 (O1), U53.14 (D5)
/IDB4: U25.2 (O0), U26.17 (B1), U42.6 (P3), U48.29 (D4), U52.15 (O5), U53.8 (D3)
/IDB5: U25.5 (O1), U26.15 (B3), U42.5 (P2), U48.28 (D5), U52.6 (O2), U53.13 (D4)
/IDB6: U25.9 (O3), U26.12 (B6), U42.4 (P1), U48.27 (D6), U52.12 (O4), U53.18 (D7)
/IDB7: U14.13 (O6b), U18.5 (Y), U25.6 (O2), U26.13 (B5), U42.3 (P0), U48.26 (D7), U53.3 (D0)
/IDB7_LATCHED: U14.14 (I6), U32.9 (Q), U55.2 (I0a)
/ISA_14M318: P1.B30 (OSC_14M318), U7.1 (I1)
/ISA_A0: P1.A31 (BA00), U36.1 (S), U55.1 (S)
/ISA_A1: P1.A30 (BA01), U34.2 (I2)
/ISA_A2: P1.A29 (BA02), U34.3 (I3)
/ISA_A4: P1.A27 (BA04), U34.4 (I4)
/ISA_A5: P1.A26 (BA05), U34.5 (I5)
/ISA_A6: P1.A25 (BA06), U34.6 (I6)
/ISA_A7: P1.A24 (BA07), U34.7 (I7)
/ISA_A8: P1.A23 (BA08), U34.1 (I1)
/ISA_A9: P1.A22 (BA09), U34.13 (IO7)
/ISA_AEN: P1.A11 (AEN), U34.14 (IO6)
/ISA_D0: P1.A9 (DB0), U36.4 (Za), U52.18 (D7), U53.5 (O1), U54.4 (D1)
/ISA_D1: P1.A8 (DB1), U36.7 (Zb), U52.3 (D0), U53.16 (O6), U54.17 (D6)
/ISA_D2: P1.A7 (DB2), U36.9 (Zd), U52.17 (D6), U53.6 (O2), U54.14 (D5)
/ISA_D3: P1.A6 (DB3), U36.12 (Zc), U52.4 (D1), U53.15 (O5), U54.7 (D2)
/ISA_D4: P1.A5 (DB4), U52.14 (D5), U53.9 (O3), U54.8 (D3), U55.4 (Za)
/ISA_D5: P1.A4 (DB5), U52.7 (D2), U53.12 (O4), U54.13 (D4), U55.12 (Zc)
/ISA_D6: P1.A3 (DB6), U52.13 (D4), U53.19 (O7), U54.3 (D0), U55.7 (Zb)
/ISA_D7: P1.A2 (DB7), U32.12 (D), U53.2 (O0), U54.18 (D7), U55.9 (Zd)
/ISA_JOY_TRIG: U30.2 (I2), U34.16 (IO4)
/ISA_OUT_LATCH: U30.13 (IO7), U53.11 (Cp)
/ISA_OUT_~OE: U31.5 (~S), U34.12 (IO8), U53.1 (OE)
/ISA_RESET: P1.B2 (RESET), U51.17 (I03)
/ISA_~IOR: P1.B14 (~IOR), U34.9 (I9)
/ISA_~IOW: P1.B13 (~IOW), U34.11 (I10)
/JOYPORT_D0: U18.15 (I4), U19.1 (OUTPUT_A), U36.3 (I1a)
/JOYPORT_D1: U18.14 (I5), U19.8 (OUTPUT_B), U36.6 (I1b)
/JOYPORT_D2: U18.13 (I6), U19.9 (OUTPUT_C), U36.10 (I1d)
/JOYPORT_D3: U18.12 (I7), U19.16 (OUTPUT_D), U36.13 (I1c)
/JOYPORT_D4: J4.2, R8.1, U18.3 (I1), U55.3 (I1a)
/JOYPORT_D5: J4.3, R9.1, U18.2 (I2), U55.13 (I1c)
/JOYPORT_D6: J4.4, R10.1, U18.1 (I3), U55.6 (I1b)
/JOYPORT_D7: J4.9, R11.1, U55.10 (I1d)
/JOY_A: C19.1, R4.1, U19.2 (TIMING_A)
/JOY_B: C22.1, R7.1, U19.7 (TIMING_B)
/JOY_C: C21.1, R6.1, U19.10 (TIMING_C)
/JOY_D: C20.1, R5.1, U19.15 (TIMING_D)
/JOY_TRIG: U19.3 (TRIGGER_A), U19.6 (TRIGGER_B), U19.11 (TRIGGER_C), U19.14 (TRIGGER_D), U30.18 (IO2)
/KEYBOARD_LATCH: U31.12 (C), U32.11 (C), U34.18 (IO2), U52.11 (Cp)
/KEYBOARD_READ: U14.15 (OEb), U30.17 (I03), U31.4 (C), U52.1 (OE)
/KEYBOARD_STROBE: U30.12 (IO8), U32.13 (~R)
/LORES: U15.10, U15.11, U15.12, U33.11 (I10)
/MAD0: U1.13 (A6), U2.13 (A6), U3.13 (A6), U4.13 (A6), U5.14 (A0), U8.19 (IO1), U20.13 (A6), U21.13 (A6), U22.13 (A6), U23.13 (A6), U24.14 (A0), U46.4 (Za)
/MAD1: U1.7 (A1), U2.7 (A1), U3.7 (A1), U4.7 (A1), U5.8 (A4), U8.14 (IO6), U20.7 (A1), U21.7 (A1), U22.7 (A1), U23.7 (A1), U24.8 (A4), U46.7 (Zb)
/MAD2: U1.5 (A0), U2.5 (A0), U3.5 (A0), U4.5 (A0), U5.6 (A6), U8.13 (IO7), U20.5 (A0), U21.5 (A0), U22.5 (A0), U23.5 (A0), U24.6 (A6), U46.9 (Zd)
/MAD3: U1.9 (A7), U2.9 (A7), U3.9 (A7), U4.9 (A7), U5.10 (A7), U20.9 (A7), U21.9 (A7), U22.9 (A7), U23.9 (A7), U24.10 (A7), U27.12 (IO8), U47.12 (Zc)
/MAD4: U1.11 (A4), U2.11 (A4), U3.11 (A4), U4.11 (A4), U5.12 (A2), U20.11 (A4), U21.11 (A4), U22.11 (A4), U23.11 (A4), U24.12 (A2), U27.15 (IO5), U47.9 (Zd)
/MAD5: U1.10 (A5), U2.10 (A5), U3.10 (A5), U4.10 (A5), U5.11 (A3), U20.10 (A5), U21.10 (A5), U22.10 (A5), U23.10 (A5), U24.11 (A3), U27.13 (IO7), U27.14 (IO6), U47.7 (Zb)
/MAD7: U1.6 (A2), U2.6 (A2), U3.6 (A2), U4.6 (A2), U5.7 (A5), U8.15 (IO5), U20.6 (A2), U21.6 (A2), U22.6 (A2), U23.6 (A2), U24.7 (A5), U46.12 (Zc)
/MAD8: U1.12 (A3), U2.12 (A3), U3.12 (A3), U4.12 (A3), U5.13 (A1), U8.12 (IO8), U20.12 (A3), U21.12 (A3), U22.12 (A3), U23.12 (A3), U24.13 (A1), U47.4 (Za)
/MDA_VIDEO: J1.7, U56.11 (I0d)
/MDB0: U5.2 (DQ1), U6.3 (D0), U20.2 (D), U20.14 (Q), U26.9 (A7)
/MDB1: U6.14 (D5), U21.2 (D), U21.14 (Q), U24.17 (DQ4), U26.6 (A4)
/MDB2: U6.13 (D4), U22.2 (D), U22.14 (Q), U24.3 (DQ2), U26.4 (A2)
/MDB3: U6.8 (D3), U23.2 (D), U23.14 (Q), U24.15 (DQ3), U26.2 (A0)
/MDB4: U1.2 (D), U1.14 (Q), U6.7 (D2), U24.2 (DQ1), U26.3 (A1)
/MDB5: U2.2 (D), U2.14 (Q), U5.17 (DQ4), U6.18 (D7), U26.5 (A3)
/MDB6: U3.2 (D), U3.14 (Q), U5.3 (DQ2), U6.4 (D1), U26.8 (A6)
/MDB7: U4.2 (D), U4.14 (Q), U5.15 (DQ3), U6.17 (D6), U26.7 (A5)
/MON_BLUE: J2.5, R14.1, U37.4 (Za)
/MON_GREEN: J2.4, R16.1, U37.7 (Zb)
/MON_HSYNC: J2.8, U15.3, U56.7 (Zb)
/MON_INTEN: J2.6, R15.1, U56.12 (Zc)
/MON_RED: J2.3, R17.1, U37.9 (Zd)
/MON_VIDEO: J2.7, U56.9 (Zd)
/MON_VSYNC: J2.9, U15.2, U56.4 (Za)
/PHI1_O: U46.15 (OE), U47.15 (OE), U48.3 (PHI1O)
/PHI2: U6.11 (Cp), U7.12 (IO8), U8.9 (I9), U10.7 (CEP), U10.10 (CET), U27.7 (I7), U48.37 (PHI2), U49.1 (I1), U51.3 (I3)
/PIXCLK2: U7.16 (IO4), U12.11 (Cp), U33.8 (I8)
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

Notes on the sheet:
16K PSEUDO-ROM
C052
async
CTRL_LATCH: 202, 203 (W)
6502 STATE MACHINE
SPEAKER
CPU
CONTROL PORT
RAM
AKA "ANALOG CLEAR"
TURN YOUR PC INTO AN APPLE ][
Counter determines read decision point
SYNC TIMING
C0E4/C0E5
Hi order ram bits
SLOT 6 SOFT SWITCHES
C056
ISA_JOY_TRIG: 200, 201 (W)
latched pins
CHARACTER LINE COUNTER
IA12
C0E2/C0E3
CHARACTER PIXEL SHIFTER
C0EE/C0EF
KEYBOARD_LATCH: 204, 205 (W)
IA9
C054
READ LATCH
VIDEO
RAM/ROM MAPPING, CAS CONTROL RESET INVERTER
Clears bit 7 of keyboard data
STATE0
IA15
BASIC CLOCK TIMING AND SOME VIDEO STUFF
C05E
6502 READ-FROM-IO-PORT STATE MACHINE
C0E0/C0E1
RDB7=1: inverse charset. RDB7=0: regular charset.
C0E8/C0E9
C050

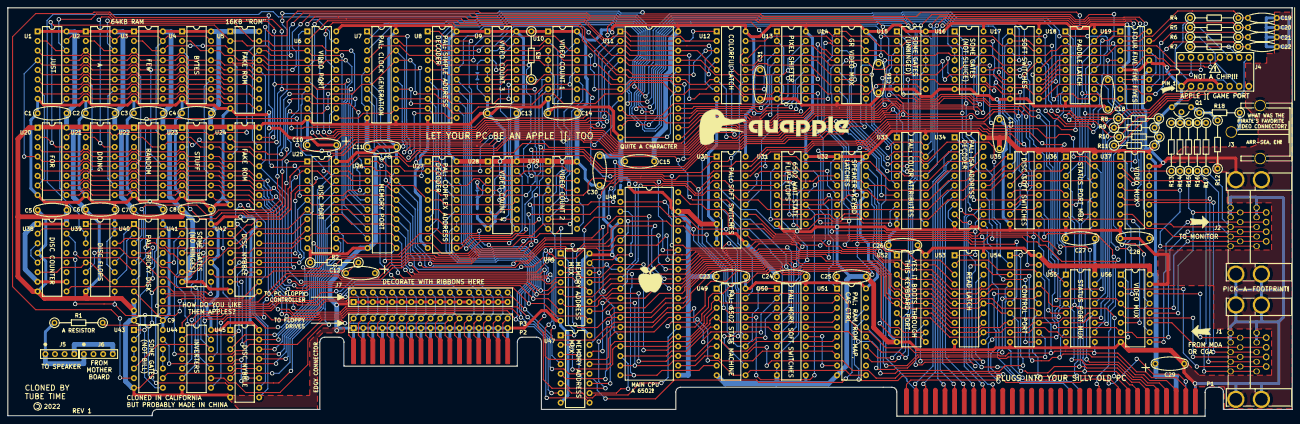
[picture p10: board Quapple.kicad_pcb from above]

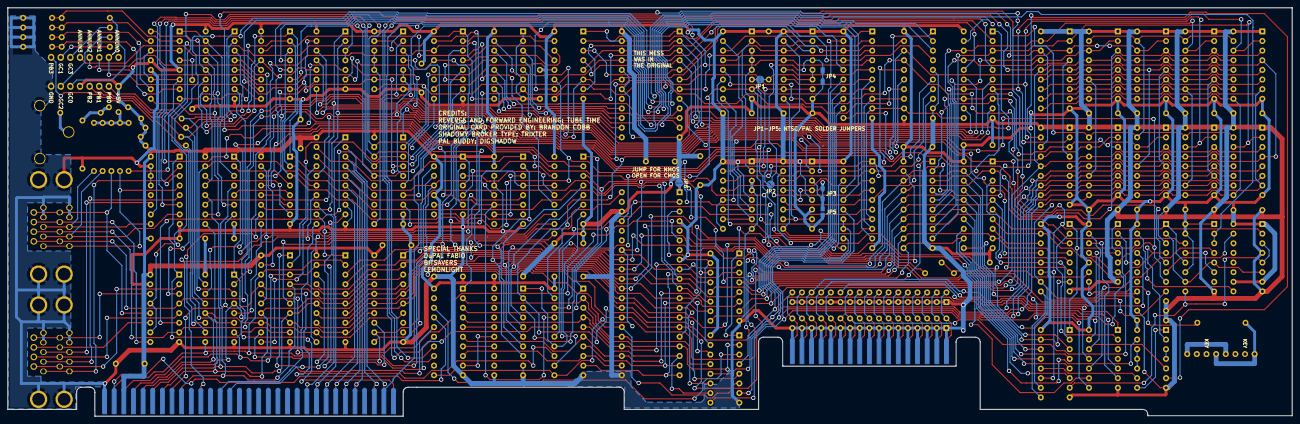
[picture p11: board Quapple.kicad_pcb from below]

Board: 2 copper layers, 338.7 x 107.7 mm, 122 parts (6 on the bottom side), 272 nets.

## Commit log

2022-05-16 update bracket, video cable description
    [bracket.dxf]
2022-07-15 Fix composite mode resistor
    [Quapple.csv, Quapple.kicad_sch]
